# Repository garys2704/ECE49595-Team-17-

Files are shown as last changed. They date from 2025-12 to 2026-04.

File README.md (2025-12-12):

# ECE49595 Senior Design - Team E17

## Samantha Gary, Adam Mack, Michael Huang, Matthew Mozingo

The wearable sound alert system is designed to alert the user to surrounding sounds and their corresponding intensities. The product will be worn around the chest and the microphones surrounding the device will take sound input and depending on the direction the sound is coming from, it will vibrate in that area on the device. Our device is designed with deaf people and people who suffer from hearing loss in mind, to give them a better awareness of their surroundings.

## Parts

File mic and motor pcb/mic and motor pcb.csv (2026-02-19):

Source: | C:\Users\tkdwp\OneDrive\Documents\sbeij\sbeij.kicad_sch
Date: | 2/13/2026 20:51
Tool: | Eeschema 7.0.10
Generator: | C:\Program Files\KiCad\7.0\bin\scripting\plugins/bom_csv_grouped_by_value.py
Component Count: | 17
Collated Components:
Item | Qty | Reference(s) | Value | LibPart | Footprint | Datasheet | DNP | Sim.Device | Sim.Pins
1 | 1 | C1 | 4.7u | Device:C_Small | Capacitor_SMD:C_0402_1005Metric | ~
2 | 1 | C2 | 0.1u | Device:C_Small | Capacitor_SMD:C_0402_1005Metric | ~
3 | 1 | C3 | C | Device:C | Capacitor_SMD:C_0402_1005Metric | ~
4 | 1 | CL1 | C_Small | Device:C_Small | Capacitor_SMD:C_0402_1005Metric | ~
5 | 1 | Diode1 | 1N4007 | Diode:1N4007 | Diode_THT:D_DO-41_SOD81_P10.16mm_Horizontal | http://www.vishay.com/docs/88503/1n4001.pdf |  | D | 1=K 2=A
6 | 1 | HD-EM1003-LW15-R1 | Motor_DC | Motor:Motor_DC |  | ~
7 | 1 | PMOF-9745W-42DQ1 | Microphone | Device:Microphone |  | ~
8 | 1 | Q1 | IRLZ34N | Transistor_FET:IRLZ34N | Package_TO_SOT_SMD:TO-263-2 | http://www.infineon.com/dgdl/irlz34npbf.pdf?fileId=5546d462533600a40153567206892720
9 | 2 | R1, RL1 | 2.2k | Device:R_US | Resistor_SMD:R_0402_1005Metric | ~
10 | 1 | R2 | 3.3k | Device:R_US | Resistor_SMD:R_0402_1005Metric | ~
11 | 1 | R3 | 330 | Device:R_US | Resistor_SMD:R_0402_1005Metric | ~
12 | 2 | R4, R6 | 390 | Device:R_US | Resistor_SMD:R_0402_1005Metric | ~
13 | 1 | R5 | 4.7k | Device:R_US | Resistor_SMD:R_0402_1005Metric | ~
14 | 1 | RB1 | 1k | Device:R_US | Resistor_SMD:R_0402_1005Metric | ~
15 | 1 | U1 | LM324 | Amplifier_Operational:LM324 | Package_SO:SOIC-8-N7_3.9x4.9mm_P1.27mm | http://www.ti.com/lit/ds/symlink/lm2902-n.pdf

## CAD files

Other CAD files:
Band assembly.iam
buckle.ipt
front_back band.ipt
side band.ipt

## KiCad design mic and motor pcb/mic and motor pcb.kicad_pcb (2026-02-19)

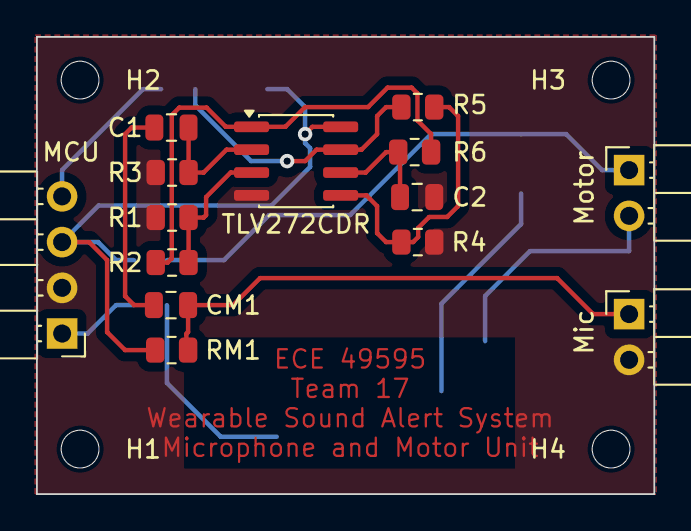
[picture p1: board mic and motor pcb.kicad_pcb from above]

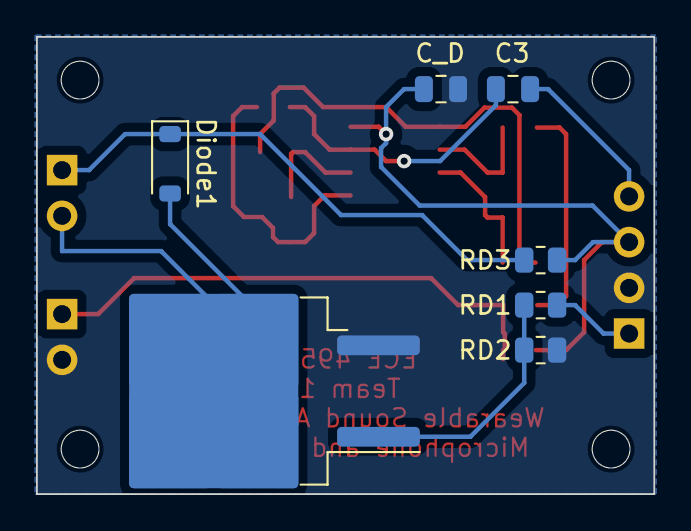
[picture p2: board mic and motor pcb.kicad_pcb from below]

Board: 2 copper layers, 34.3 x 25.4 mm, 25 parts (7 on the bottom side), 15 nets.

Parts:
C1: 4.7u; C_0805_2012Metric
C2: 0.1u; C_0805_2012Metric
C3: 0.01u; C_0805_2012Metric
CM1: C_Small; C_0805_2012Metric
C_D: C_Small; C_0805_2012Metric
Diode1: 1N5819; D_SOD-123
H1, H2, H3, H4: MountingHole; MountingHole_2.1mm
MCU: Conn_01x04_Pin; PinHeader_1x04_P2.54mm_Horizontal
Mic: Conn_01x02_Pin; PinHeader_1x02_P2.54mm_Horizontal
Motor: Conn_01x02_Pin; PinHeader_1x02_P2.54mm_Horizontal
Q1: IRLZ34N; TO-263-2
R1: 2.2k; R_0805_2012Metric
R2: 3.3k; R_0805_2012Metric
R3: 330; R_0805_2012Metric
R4, R6: 390; R_0805_2012Metric
R5: 4.7k; R_0805_2012Metric
RD1: 1k; R_0805_2012Metric
RD2: 10k; R_0805_2012Metric
RD3: 10; R_0805_2012Metric
RM1: 2.2k; R_0805_2012Metric
U2: TLV272CDR; SOIC-8_3.9x4.9mm_P1.27mm

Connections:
/Amp_out: C3.2, MCU.4
/Mic_pwr: CM1.2, Mic.1, RM1.2
/MotorPWMinput: MCU.1, RD1.1
/Motor_drain: Diode1.2 (A), Motor.2, Q1.2 (D)
/Motor_pwr: Diode1.1 (K), Motor.1, RD3.1
GND: C2.1, C_D.1, MCU.2, Mic.2, Q1.3 (S), R1.2, R3.2, R4.2, RD2.2, U2.4 (V-)
unnamed: C1.1, CM1.1
unnamed: C3.1, R5.1, U2.7
unnamed: Q1.1 (G), RD1.2, RD2.1
unnamed: R2.1, R6.2, U2.1
unnamed: R1.1, R2.2, U2.3 (+)
unnamed: C1.2, R3.1, U2.2 (-)
unnamed: R4.1, R5.2, U2.5 (+)
unnamed: C2.2, R6.1, U2.6 (-)
VCC: C_D.2, MCU.3, RD3.2, RM1.1, U2.8 (V+)

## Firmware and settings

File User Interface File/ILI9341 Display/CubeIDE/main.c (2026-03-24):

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
/* Includes ------------------------------------------------------------------*/
#include "main.h"
#include <string.h>
#include "ili9341.h"
#include "ili9341_GFX.h"
#include "fonts.h"

/* USER CODE BEGIN PD */
#define TFT_WIDTH  240
#define TFT_HEIGHT 320
/* USER CODE END PD */

#if defined ( __ICCARM__ ) /*!< IAR Compiler */
#pragma location=0x2007c000
ETH_DMADescTypeDef  DMARxDscrTab[ETH_RX_DESC_CNT]; /* Ethernet Rx DMA Descriptors */
#pragma location=0x2007c0a0
ETH_DMADescTypeDef  DMATxDscrTab[ETH_TX_DESC_CNT]; /* Ethernet Tx DMA Descriptors */

#elif defined ( __CC_ARM )  /* MDK ARM Compiler */

__attribute__((at(0x2007c000))) ETH_DMADescTypeDef  DMARxDscrTab[ETH_RX_DESC_CNT]; /* Ethernet Rx DMA Descriptors */
__attribute__((at(0x2007c0a0))) ETH_DMADescTypeDef  DMATxDscrTab[ETH_TX_DESC_CNT]; /* Ethernet Tx DMA Descriptors */

#elif defined ( __GNUC__ ) /* GNU Compiler */

ETH_DMADescTypeDef DMARxDscrTab[ETH_RX_DESC_CNT] __attribute__((section(".RxDecripSection"))); /* Ethernet Rx DMA Descriptors */
ETH_DMADescTypeDef DMATxDscrTab[ETH_TX_DESC_CNT] __attribute__((section(".TxDecripSection")));   /* Ethernet Tx DMA Descriptors */
#endif

ETH_TxPacketConfig TxConfig;

ETH_HandleTypeDef heth;

I2S_HandleTypeDef hi2s2;
DMA_HandleTypeDef hdma_spi2_tx;

UART_HandleTypeDef huart3;

PCD_HandleTypeDef hpcd_USB_OTG_FS;

void SystemClock_Config(void);
static void MX_GPIO_Init(void);
static void MX_DMA_Init(void);
static void MX_ETH_Init(void);
static void MX_USART3_UART_Init(void);
static void MX_USB_OTG_FS_PCD_Init(void);
static void MX_I2S2_Init(void);
/**
  * @brief  The application entry point.
  * @retval int
  */
int main(void)
{

  /* USER CODE BEGIN 1 */

	//ILI9341_Draw_Bar();
	ILI9341_Draw_Battery(ILI9341_Green);
  /* USER CODE END 1 */

  /* MCU Configuration--------------------------------------------------------*/

  /* Reset of all peripherals, Initializes the Flash interface and the Systick. */
	HAL_Init();

  /* USER CODE BEGIN Init */
	ili9341_Init();
	ILI9341_Fill_Screen(ILI9341_Black);
	ILI9341_Draw_Text(0, 0, "Hello", Font_11x8, ILI9341_White);

	int32_t volume = 20;
	int32_t sensi = 40;
	int32_t test = 10;

	int32_t menuIndex = 0;
	int32_t menuVal = 0;
	int32_t lastMenuIndex = 0;

	int32_t oldStat = 0;
	int32_t oldBatt = 0;

	static int32_t turn_enable = 1;
	static int32_t turnDir = 1;

	static int32_t menuFrames[] = {0, 1};

	static int32_t* stat = NULL;
	static int32_t* batt = NULL;

  /* USER CODE END Init */

  /* Configure the system clock */
  SystemClock_Config();

  /* Initialize all configured peripherals */
  MX_GPIO_Init();
  MX_DMA_Init();
  MX_ETH_Init();
  MX_USART3_UART_Init();
  MX_USB_OTG_FS_PCD_Init();
  MX_I2S2_Init();
  /* Infinite loop */
  /* USER CODE BEGIN WHILE */
  while (1)
  {
	  if(HAL_GPIO_ReadPin(GPIOF, GPIO_PIN_10) == GPIO_PIN_RESET) {
		  menuIndex++;
	  }
	  else if(HAL_GPIO_ReadPin(GPIOF, GPIO_PIN_5) == GPIO_PIN_RESET) {
	      menuIndex--;
	  }

	  if(menuIndex != lastMenuIndex) {
	      menuVal = menuFrames[abs(menuIndex % 2)];
	      stat = setStat(menuVal);

	      MenuText(menuVal);
	      HAL_Delay(50);

	      MenuBar(stat);
	      HAL_Delay(50);

	      lastMenuIndex = menuIndex;
	    }
	  if(batt != oldBatt) {

	  }
	  HAL_Delay(30);

    /* USER CODE END WHILE */

    /* USER CODE BEGIN 3 */
  }
  /* USER CODE END 3 */
}

void MenuText(int menuVal) {
    ILI9341_Draw_Rectangle_Filled(0, 0, TFT_WIDTH, 50, ILI9341_Black);

    if(menuVal == 0){
        ILI9341_Draw_Text(0, 0, "Volume", Font_11x18, ILI9341_White);
    }
    else if(menuVal == 1){
        ILI9341_Draw_Text(0, 0, "Sensitivity", Font_11x18, ILI9341_White);
    }
}

void MenuBar(int* stat) {
    int cx = TFT_WIDTH / 2;
    int base = TFT_HEIGHT - 50;

    if(*stat > oldStat){
        ILI9341_Draw_Rectangle_Filled(cx - 10, base - *stat, 20, *stat - oldStat, ILI9341_Green);
    }
    else {
        ILI9341_Draw_Rectangle_Filled(cx - 10, base - oldStat, 20, oldStat - *stat, ILI9341_Black);
    }

    ILI9341_Draw_Rectangle(cx - 10, base - 200, cx + 10, base, ILI9341_Green);

    oldStat = *stat;
}

void BatteryBar(int* batt) {
    int cx = TFT_WIDTH / 2;
    int base = TFT_WIDTH - 200;

    if(*batt > oldBatt){
        ILI9341_Draw_Rectangle_Filled(oldBatt - base, TFT_HEIGHT - 80, *batt - oldBatt, 60, ILI9341_Green);
    }
    else {
        ILI9341_Draw_Rectangle_Filled(*batt - base, TFT_HEIGHT - 80, oldBatt - *batt, 60, ILI9341_Black);
    }

    ILI9341_Draw_Rectangle(base, TGT_HEIGHT - 80, 120, 60, ILI9341_Green);

    oldBatt = *batt;
}


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


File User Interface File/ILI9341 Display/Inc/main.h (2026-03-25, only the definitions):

#define USER_Btn_Pin GPIO_PIN_13
#define USER_Btn_GPIO_Port GPIOC
#define MCO_Pin GPIO_PIN_0
#define MCO_GPIO_Port GPIOH
#define RIGHT_BTN_Pin GPIO_PIN_0
#define RIGHT_BTN_GPIO_Port GPIOC
#define RMII_MDC_Pin GPIO_PIN_1
#define RMII_MDC_GPIO_Port GPIOC
#define RMII_REF_CLK_Pin GPIO_PIN_1
#define RMII_REF_CLK_GPIO_Port GPIOA
#define RMII_MDIO_Pin GPIO_PIN_2
#define RMII_MDIO_GPIO_Port GPIOA
#define LEFT_BTN_Pin GPIO_PIN_3
#define LEFT_BTN_GPIO_Port GPIOA
#define ENC_BTN_Pin GPIO_PIN_5
#define ENC_BTN_GPIO_Port GPIOA
#define RMII_CRS_DV_Pin GPIO_PIN_7
#define RMII_CRS_DV_GPIO_Port GPIOA
#define RMII_RXD0_Pin GPIO_PIN_4
#define RMII_RXD0_GPIO_Port GPIOC
#define RMII_RXD1_Pin GPIO_PIN_5
#define RMII_RXD1_GPIO_Port GPIOC
#define LD1_Pin GPIO_PIN_0
#define LD1_GPIO_Port GPIOB
#define DBG_LED_3_Pin GPIO_PIN_0
#define DBG_LED_3_GPIO_Port GPIOG
#define RMII_TXD1_Pin GPIO_PIN_13
#define RMII_TXD1_GPIO_Port GPIOB
#define LD3_Pin GPIO_PIN_14
#define LD3_GPIO_Port GPIOB
#define STLK_RX_Pin GPIO_PIN_8
#define STLK_RX_GPIO_Port GPIOD
#define STLK_TX_Pin GPIO_PIN_9
#define STLK_TX_GPIO_Port GPIOD
#define USB_PowerSwitchOn_Pin GPIO_PIN_6
#define USB_PowerSwitchOn_GPIO_Port GPIOG
#define USB_OverCurrent_Pin GPIO_PIN_7
#define USB_OverCurrent_GPIO_Port GPIOG
#define USB_SOF_Pin GPIO_PIN_8
#define USB_SOF_GPIO_Port GPIOA
#define USB_VBUS_Pin GPIO_PIN_9
#define USB_VBUS_GPIO_Port GPIOA
#define USB_ID_Pin GPIO_PIN_10
#define USB_ID_GPIO_Port GPIOA
#define USB_DM_Pin GPIO_PIN_11
#define USB_DM_GPIO_Port GPIOA
#define USB_DP_Pin GPIO_PIN_12
#define USB_DP_GPIO_Port GPIOA
#define TMS_Pin GPIO_PIN_13
#define TMS_GPIO_Port GPIOA
#define TCK_Pin GPIO_PIN_14
#define TCK_GPIO_Port GPIOA
#define DBG_LED1_Pin GPIO_PIN_0
#define DBG_LED1_GPIO_Port GPIOD
#define DBG_LED_2_Pin GPIO_PIN_1
#define DBG_LED_2_GPIO_Port GPIOD
#define RMII_TX_EN_Pin GPIO_PIN_11
#define RMII_TX_EN_GPIO_Port GPIOG
#define RMII_TXD0_Pin GPIO_PIN_13
#define RMII_TXD0_GPIO_Port GPIOG
#define SWO_Pin GPIO_PIN_3
#define SWO_GPIO_Port GPIOB
#define LD2_Pin GPIO_PIN_7
#define LD2_GPIO_Port GPIOB

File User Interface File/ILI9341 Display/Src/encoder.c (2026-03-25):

#include "stm32f7xx_hal.h"
#include "encoder.h"
#include "tim.h"
#include "gpio.h"
#include "main.h"
#include "ui_event.h"

#define ENC_TIM htim3

#define COUNTS_PER_DETENT 2

// button debounce timing -- will get button functionality later
#define DEBOUNCE_MS 20
#define LONGPRESS_MS 1000

static int32_t prev = 0;
static int32_t accum = 0;
static uint32_t btnLastChange_ms = 0;
static uint32_t btnPressStart_ms = 0;
static bool btnStableState = true;
static bool btnLastReport = true;

int32_t getCount(void) {
    return (int32_t)__HAL_TIM_GET_COUNTER(&ENC_TIM);
}

static inline uint32_t getms(void) {
	return HAL_GetTick();
}

// get timer count
void encoderInit(void) {
	HAL_TIM_Encoder_Start(&ENC_TIM, TIM_CHANNEL_ALL);
	prev = getCount();
	btnLastReport = (HAL_GPIO_ReadPin(ENC_BTN_GPIO_Port, ENC_BTN_Pin) == GPIO_PIN_SET); // released
	btnStableState = btnLastReport;
	btnLastChange_ms = getms();
}

static bool btnSample(bool* outClick, bool* outLongpress) {
  *outClick = false;
  *outLongpress = false;

  bool rawRelease = (HAL_GPIO_ReadPin(ENC_BTN_GPIO_Port, ENC_BTN_Pin) == GPIO_PIN_SET);
  uint32_t t = getms();

  // debounce & detect changes in raw input
  if (rawRelease != btnLastReport) {
    btnLastReport = rawRelease;
    btnLastChange_ms = t;
  }

  // if stable long enough, accept new stable state
  if ((t - btnLastChange_ms) >= DEBOUNCE_MS && rawRelease != btnStableState) {
    btnStableState = rawRelease;

    // transition from released -> pressed
    if (!btnStableState) {
      btnPressStart_ms = t;
    } else {
      // transition from pressed -> released
      uint32_t held = t - btnPressStart_ms;
      if (held >= LONGPRESS_MS) {
        *outLongpress = true;
      } else {
        *outClick = true;
      }
    }
    return true;
  }

  return false;
}

// gets the raw total movement of the encoder
int32_t getDelta(void){
	int32_t now = getCount();
	int32_t delta = now - prev;

	// wrapping
	if (delta > 32767) delta -= 65536;
	if (delta < -32768) delta += 65536;

	prev = now;
	return delta;
}

// converts raw encoder movement into detents
int32_t getDetents(void){
	int32_t delta = getDelta();
	accum += delta;

	int32_t detents = accum / COUNTS_PER_DETENT;
	accum -= detents * COUNTS_PER_DETENT;
	return detents;
}

// periodically check the encoder for new events
bool encoderCheck(EncEvent* out){
	if (!out) return false;

	// logic for turns
	int32_t detents = getDetents();
	if (detents != 0) {
		out->type = ENC_EVT_ROTATE;
		out->steps = detents;
		return true;
	}

	// logic for button press
	bool outClick = false;
	bool outPress = false;
	bool btnChange = btnSample(&outClick, &outPress);
	if (btnChange) {
		if (outClick){
			out->type = ENC_EVT_CLICK;
			out->steps = 0;
			return true;
		}
		else if (outPress){
			out->type = ENC_EVT_LONGPRESS;
			out->steps = 0;
			return true;
		}
	}
	return false;
}

bool Encoder_PollUi(UiEvent* out)
{
  EncEvent ev;
  if (!out) return false;
  if (!encoderCheck(&ev)) return false;

  out->value = 0;
  switch (ev.type) {
    case ENC_EVT_ROTATE:
    	out->type = UI_EVT_ENC_ROTATE;
    	out->value = ev.steps;
    	return true;
    case ENC_EVT_CLICK:
    	out->type = UI_EVT_ENC_CLICK;
    	return true;
    case ENC_EVT_LONGPRESS:
		out->type = UI_EVT_ENC_LONGPRESS;
		return true;
    default:
    	return false;
  }
}

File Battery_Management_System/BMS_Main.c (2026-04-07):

#include "BMS.h"



int main(void)
{
	MX_GPIO_Init();
	MX_I2C1_Init();


	if (MAX17055_Init(&hi2c1) != HAL_OK)
 	{
        //Error_Handler();
		print("BMS Init Failed");
 	}

	void Battery_Task(void)
	{
      uint16_t soc_raw;
      float soc;

      if (MAX17055_ReadReg(&hi2c1, REG_REPSOC, &soc_raw) == HAL_OK)
      {
    	  soc = soc_raw / 256.0f;
      }
	}

	//Main Loop
	while (1)
	{
		Battery_Task();
		HAL_Delay(1000);
	}
}

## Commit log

2026-01-20 Added initial PCB schematic
    Looked into what components have existing symbols and/or footprints in KiCad
    [Wearable Sound Alert System.kicad_pcb, Wearable Sound Alert System.kicad_sch]
2026-02-19 Amplifier and boost converter kicad
    [pwm amplifier.kicad_pcb, pwm amplifier.kicad_sch]
2026-02-19 Mic and motor pcb
    [mic and motor pcb.csv, mic and motor pcb.kicad_pcb, mic and motor pcb.kicad_sch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]
2026-03-24 Create User Interface
    Code for the buttons, rotary encoder, and ili9341 display.
2026-03-27 Updated Graphics functions in GFX
    Added functions for menu and battery bar display.
2026-03-27 Add new functions for menu and battery
2026-04-07 Added Battery Management System

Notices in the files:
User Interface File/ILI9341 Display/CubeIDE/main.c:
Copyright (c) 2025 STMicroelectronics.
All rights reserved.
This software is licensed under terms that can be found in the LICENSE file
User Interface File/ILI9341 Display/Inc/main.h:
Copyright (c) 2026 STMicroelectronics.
